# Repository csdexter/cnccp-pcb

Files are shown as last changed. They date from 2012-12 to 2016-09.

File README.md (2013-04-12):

#CNC Control Panel: Schematics and Boards#

(C) 2012 Radu - Eosif Mihailescu <radu.mihailescu@linux360.ro>

All files in this repository except `radu-collected.lbr` are licensed under the
**GNU Generic Public License v3**, a copy of whose text can be accessed
 [here](http://www.gnu.org/licenses/gpl.html).

`radu-collected.lbr` alone is hereby licensed under the **Modified BSD (3-clause) License**, a copy of whose text can be found in the `radu-collected.lbr.license` file.

This repository contains [EDA](http://en.wikipedia.org/wiki/Electronic_design_automation) source files for all of the boards in the *CNC Control Panel* project in CadSoft Eagle 6 format. Only the `.SCH` (schematic) and `.BRD` (board) files are provided as all data needed for manufacturing can easily be derived from the former. No guarantee is made as to which minor version of Eagle was used to save the file, but it *may* be the latest at the time of this writing.

The board description files *may* contain routing information or be supplied unrouted. In the former case, the routing artwork *may* have been generated by either Eagle's internal autorouter or [FreeRouting](http://www.freerouting.net/). A 25mil routing grid and 10/10mil trace/space settings will have been used in both cases.

All files included here are compatible with the free version of Eagle (i.e. describe PCBs having no more than 2 layers and measuring no more than 10cm by 8cm each).

Git tags will be used to mark specific revisions that were actually manufactured so that a correspondence between the evolution of the sources and the status of physical by-products can be maintained.

##WARNING##
*Unless and until explictily noted otherwise, the engineering materials here are laboratory quality and neither intended for manufacturing in production quantities nor for distribution (e.g. as kits) to end-users. The design data here does not explicitly follow any widely-accepted safety/security/EMI regulation or standard, therefore any manufacturing and/or usage in connection with live equipment is entirely at your own risk.*

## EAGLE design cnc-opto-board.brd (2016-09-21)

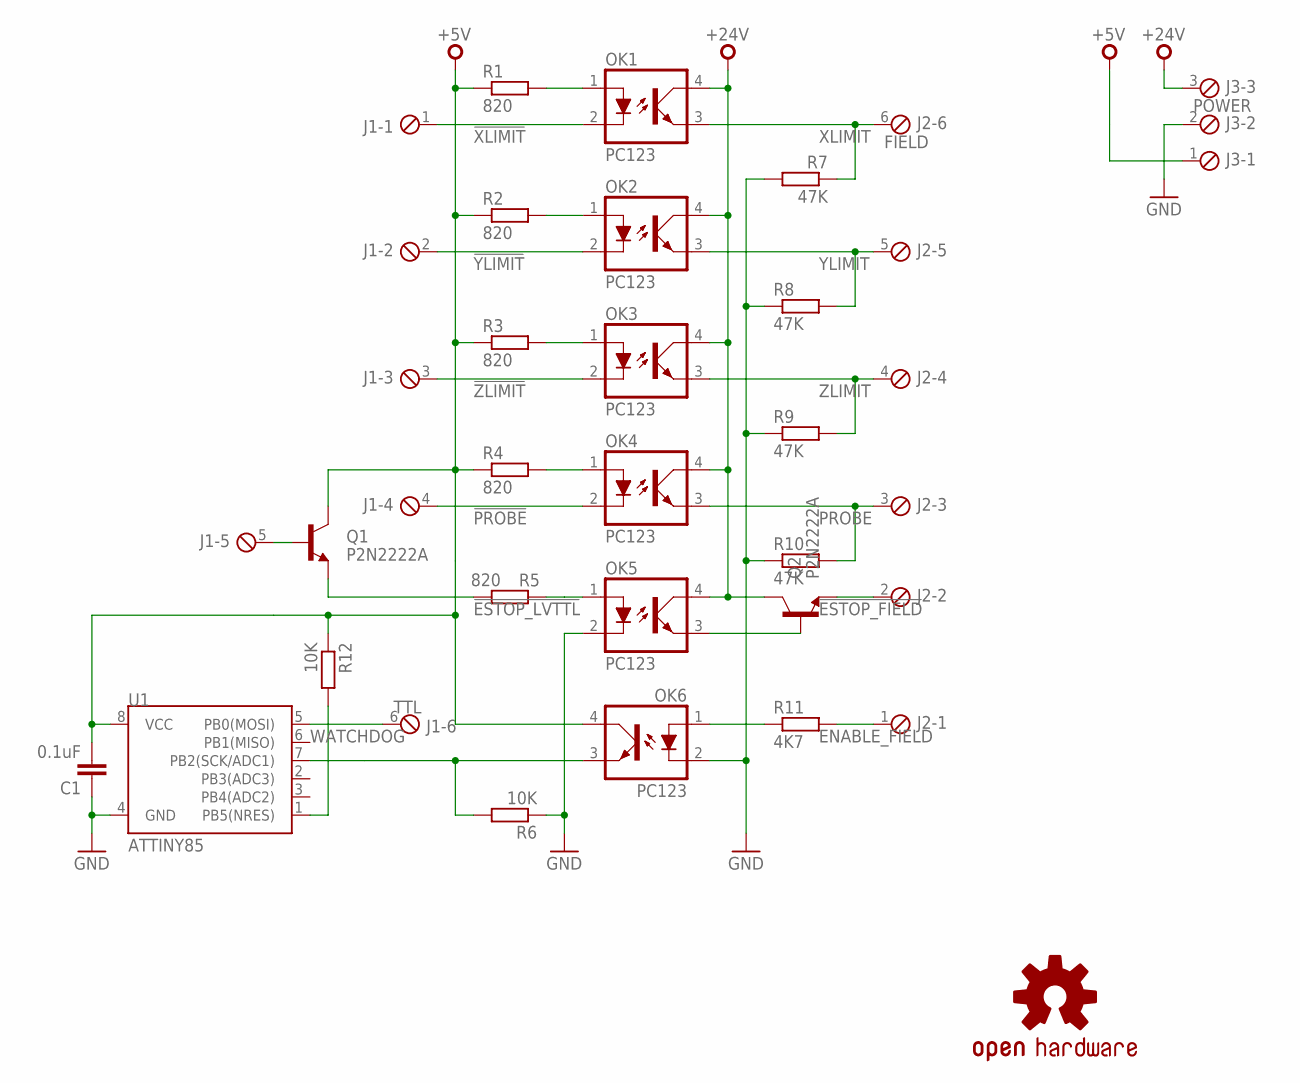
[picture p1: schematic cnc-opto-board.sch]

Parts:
C1: 0.1uF; C050-025X075
J1: TTL; MKDS06
J2: FIELD; MKDS06
J3: POWER; MKDS03
LOGO1: OSHW-LOGOL; OSHW-LOGO-L
OK1, OK2, OK3, OK4, OK5, OK6: PC123; DIL04
Q1, Q2: P2N2222A; TO-92
R1, R2, R3, R4, R5: 820; 0207/10
R6, R12: 10K; 0207/10
R7, R8, R9, R10: 47K; 0207/10
R11: 4K7; 0207/10
U1: ATTINY85; DIL08

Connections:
!ESTOP_FIELD: J2.2, Q2.3 (E)
!ESTOP_LVTTL: OK5.1 (A), R5.1
!PROBE: J1.4, OK4.2 (C)
!XLIMIT: J1.1, OK1.2 (C)
!YLIMIT: J1.2, OK2.2 (C)
!ZLIMIT: J1.3, OK3.2 (C)
+5V: C1.2, J3.1, OK6.4 (COL), Q1.1 (C), R1.1, R2.1, R3.1, R4.1, R12.1, U1.8 (VCC)
+24V: J3.3, OK1.4 (COL), OK2.4 (COL), OK3.4 (COL), OK4.4 (COL), OK5.4 (COL), Q2.1 (C)
ENABLE_FIELD: J2.1, R11.2
ENABLE_TTL: OK6.3 (EMIT), R6.2, U1.7 (PB2(SCK/ADC1))
GND: C1.1, J3.2, OK5.2 (C), OK6.2 (C), R6.1, R7.2, R8.1, R9.1, R10.1, U1.4 (GND)
unnamed: OK1.1 (A), R1.2
unnamed: OK2.1 (A), R2.2
unnamed: OK3.1 (A), R3.2
unnamed: OK4.1 (A), R4.2
unnamed: Q1.3 (E), R5.2
unnamed: OK6.1 (A), R11.1
unnamed: J1.5, Q1.2 (B)
unnamed: OK5.3 (EMIT), Q2.2 (B)
unnamed: R12.2, U1.1 (PB5(NRES))
PROBE: J2.3, OK4.3 (EMIT), R10.2
WATCHDOG: J1.6, U1.5 (PB0(MOSI))
XLIMIT: J2.6, OK1.3 (EMIT), R7.1
YLIMIT: J2.5, OK2.3 (EMIT), R8.2
ZLIMIT: J2.4, OK3.3 (EMIT), R9.2

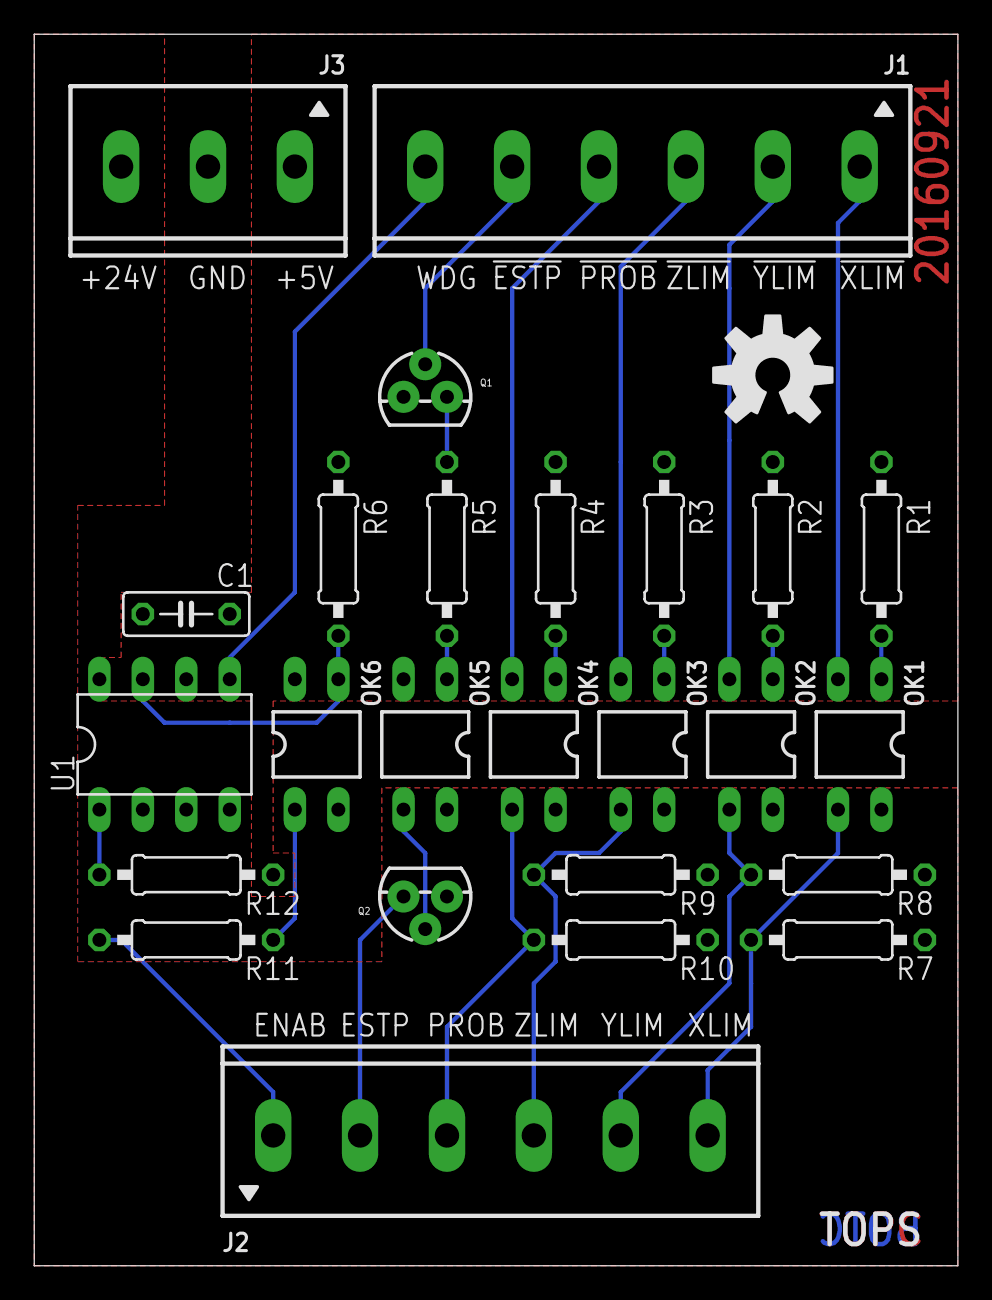
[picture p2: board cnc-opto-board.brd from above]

Board: 2 copper layers, 54.0 x 72.0 mm, 26 parts (0 on the bottom side), 25 nets.

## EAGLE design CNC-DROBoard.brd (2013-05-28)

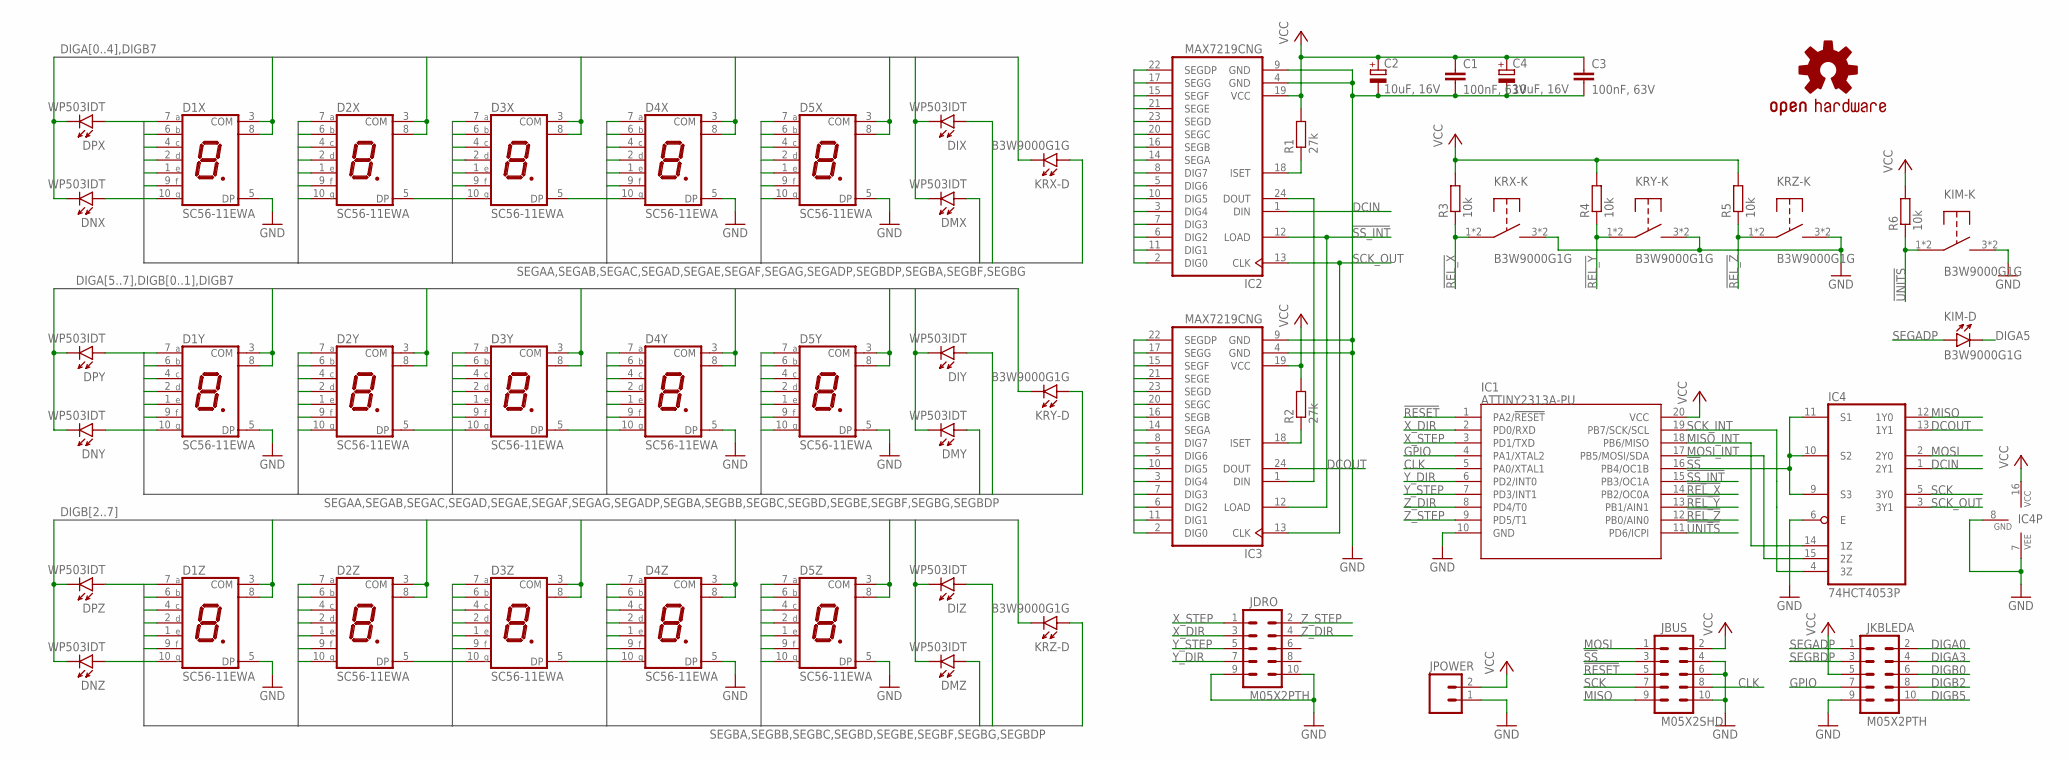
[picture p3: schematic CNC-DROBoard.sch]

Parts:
C1, C3: 100nF, 63V; C050-025X075
C2, C4: 10uF, 16V; E2,5-6E
D1X, D1Y, D1Z, D2X, D2Y, D2Z, D3X, D3Y, D3Z, D4X, D4Y, D4Z, D5X, D5Y, D5Z: SC56-11EWA; SA52-11
DIX: WP503IDT; AXIAL__GENERIC_SQ_5X5
DIY: WP503IDT; AXIAL__GENERIC_SQ_5X5
DIZ: WP503IDT; AXIAL__GENERIC_SQ_5X5
DMX: WP503IDT; AXIAL__GENERIC_SQ_5X5
DMY: WP503IDT; AXIAL__GENERIC_SQ_5X5
DMZ: WP503IDT; AXIAL__GENERIC_SQ_5X5
DNX: WP503IDT; AXIAL__GENERIC_SQ_5X5
DNY: WP503IDT; AXIAL__GENERIC_SQ_5X5
DNZ: WP503IDT; AXIAL__GENERIC_SQ_5X5
DPX: WP503IDT; AXIAL__GENERIC_SQ_5X5
DPY: WP503IDT; AXIAL__GENERIC_SQ_5X5
DPZ: WP503IDT; AXIAL__GENERIC_SQ_5X5
IC1: ATTINY2313A-PU; DIL20
IC2, IC3: MAX7219CNG; DIL24-3
IC4: 74HCT4053P; DIL16
JBUS: M05X2SHD; 2X5-SHROUDED
JDRO: M05X2PTH; AVR_ICSP
JKBLEDA: M05X2PTH; AVR_ICSP
JPOWER: M02POLAR; MOLEX-1X2
KIM: B3W9000G1G; OMRON_B3W90
KRX: B3W9000G1G; OMRON_B3W90
KRY: B3W9000G1G; OMRON_B3W90
KRZ: B3W9000G1G; OMRON_B3W90
R1, R2: 27k; 0207/10
R3, R4, R5, R6: 10k; 0207/10
U$1: SPARKFUN_OSHW-LOGOL; SPARKFUN_OSHW-LOGO-L

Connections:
!REL_X: IC1.14 (PB2/OC0A), KRX.1, KRX.2, R3.1
!REL_Y: IC1.13 (PB1/AIN1), KRY.1, KRY.2, R4.1
!REL_Z: IC1.12 (PB0/AIN0), KRZ.1, KRZ.2, R5.1
!RESET: IC1.1 (PA2/!RESET), JBUS.5
!SS: IC1.16 (PB4/OC1B), IC4.9 (S3), IC4.10 (S2), IC4.11 (S1), JBUS.3
!SS_INT: IC1.15 (PB3/OC1A), IC2.12 (LOAD), IC3.12 (LOAD)
!UNITS: IC1.11 (PD6/ICPI), KIM.1, KIM.2, R6.1
CLK: IC1.5 (PA0/XTAL1), JBUS.8
DCIN: IC2.1 (DIN), IC4.1 (2Y1)
DCOUT: IC3.24 (DOUT), IC4.13 (1Y1)
DIGA0: D1X.3 (COM), D1X.8 (COM), IC2.2 (DIG0), JKBLEDA.2
DIGA1: D2X.3 (COM), D2X.8 (COM), IC2.11 (DIG1)
DIGA2: D3X.3 (COM), D3X.8 (COM), IC2.6 (DIG2)
DIGA3: D4X.3 (COM), D4X.8 (COM), IC2.7 (DIG3), JKBLEDA.4
DIGA4: D5X.3 (COM), D5X.8 (COM), IC2.3 (DIG4), KRX.6 (K)
DIGA5: D1Y.3 (COM), D1Y.8 (COM), IC2.10 (DIG5), KIM.6 (K)
DIGA6: D2Y.3 (COM), D2Y.8 (COM), IC2.5 (DIG6)
DIGA7: D3Y.3 (COM), D3Y.8 (COM), IC2.8 (DIG7)
DIGB0: D4Y.3 (COM), D4Y.8 (COM), IC3.2 (DIG0), JKBLEDA.6
DIGB1: D5Y.3 (COM), D5Y.8 (COM), IC3.11 (DIG1), KRY.6 (K)
DIGB2: D1Z.3 (COM), D1Z.8 (COM), IC3.6 (DIG2), JKBLEDA.8
DIGB3: D2Z.3 (COM), D2Z.8 (COM), IC3.7 (DIG3)
DIGB4: D3Z.3 (COM), D3Z.8 (COM), IC3.3 (DIG4)
DIGB5: D4Z.3 (COM), D4Z.8 (COM), IC3.10 (DIG5), JKBLEDA.10
DIGB6: D5Z.3 (COM), D5Z.8 (COM), IC3.5 (DIG6), KRZ.6 (K)
DIGB7: DIX.2 (K), DIY.2 (K), DIZ.2 (K), DMX.2 (K), DMY.2 (K), DMZ.2 (K), DNX.2 (K), DNY.2 (K), DNZ.2 (K), DPX.2 (K), DPY.2 (K), DPZ.2 (K), IC3.8 (DIG7)
GND: C1.2, C2.-, C3.2, C4.-, D1X.5 (DP), D1Y.5 (DP), D1Z.5 (DP), D4X.5 (DP), D4Y.5 (DP), D4Z.5 (DP), D5X.5 (DP), D5Y.5 (DP), D5Z.5 (DP), IC1.10 (GND), IC2.4 (GND), IC2.9 (GND), IC3.4 (GND), IC3.9 (GND), IC4.6 (E), IC4.7 (VEE), IC4.8 (GND), JBUS.4, JBUS.6, JBUS.10, JDRO.9, JDRO.10, JKBLEDA.9, JPOWER.1, KIM.3, KIM.4, KRX.3, KRX.4, KRY.3, KRY.4, KRZ.3, KRZ.4
GPIO: IC1.4 (PA1/XTAL2), JKBLEDA.7
MISO: IC4.12 (1Y0), JBUS.9
MISO_INT: IC1.18 (PB6/MISO), IC4.14 (1Z)
MOSI: IC4.2 (2Y0), JBUS.1
MOSI_INT: IC1.17 (PB5/MOSI/SDA), IC4.15 (2Z)
unnamed: IC2.24 (DOUT), IC3.1 (DIN)
unnamed: IC2.18 (ISET), R1.1
unnamed: IC3.18 (ISET), R2.1
SCK: IC4.5 (3Y0), JBUS.7
SCK_INT: IC1.19 (PB7/SCK/SCL), IC4.4 (3Z)
SCK_OUT: IC2.13 (CLK), IC3.13 (CLK), IC4.3 (3Y1)
SEGAA: D1X.7 (A), D1Y.7 (A), D2X.7 (A), D2Y.7 (A), D3X.7 (A), D3Y.7 (A), D4X.7 (A), D5X.7 (A), IC2.14 (SEGA)
SEGAB: D1X.6 (B), D1Y.6 (B), D2X.6 (B), D2Y.6 (B), D3X.6 (B), D3Y.6 (B), D4X.6 (B), D5X.6 (B), IC2.16 (SEGB)
SEGAC: D1X.4 (C), D1Y.4 (C), D2X.4 (C), D2Y.4 (C), D3X.4 (C), D3Y.4 (C), D4X.4 (C), D5X.4 (C), IC2.20 (SEGC)
SEGAD: D1X.2 (D), D1Y.2 (D), D2X.2 (D), D2Y.2 (D), D3X.2 (D), D3Y.2 (D), D4X.2 (D), D5X.2 (D), IC2.23 (SEGD)
SEGADP: D2X.5 (DP), D2Y.5 (DP), D3X.5 (DP), D3Y.5 (DP), IC2.22 (SEGDP), JKBLEDA.1, KIM.5 (A), KRX.5 (A)
SEGAE: D1X.1 (E), D1Y.1 (E), D2X.1 (E), D2Y.1 (E), D3X.1 (E), D3Y.1 (E), D4X.1 (E), D5X.1 (E), IC2.21 (SEGE)
SEGAF: D1X.9 (F), D1Y.9 (F), D2X.9 (F), D2Y.9 (F), D3X.9 (F), D3Y.9 (F), D4X.9 (F), D5X.9 (F), IC2.15 (SEGF)
SEGAG: D1X.10 (G), D1Y.10 (G), D2X.10 (G), D2Y.10 (G), D3X.10 (G), D3Y.10 (G), D4X.10 (G), D5X.10 (G), IC2.17 (SEGG)
SEGBA: D1Z.7 (A), D2Z.7 (A), D3Z.7 (A), D4Y.7 (A), D4Z.7 (A), D5Y.7 (A), D5Z.7 (A), DNX.1 (A), IC3.14 (SEGA)
SEGBB: D1Z.6 (B), D2Z.6 (B), D3Z.6 (B), D4Y.6 (B), D4Z.6 (B), D5Y.6 (B), D5Z.6 (B), DPY.1 (A), IC3.16 (SEGB)
SEGBC: D1Z.4 (C), D2Z.4 (C), D3Z.4 (C), D4Y.4 (C), D4Z.4 (C), D5Y.4 (C), D5Z.4 (C), DNY.1 (A), IC3.20 (SEGC)
SEGBD: D1Z.2 (D), D2Z.2 (D), D3Z.2 (D), D4Y.2 (D), D4Z.2 (D), D5Y.2 (D), D5Z.2 (D), DPZ.1 (A), IC3.23 (SEGD)
SEGBDP: D2Z.5 (DP), D3Z.5 (DP), DPX.1 (A), IC3.22 (SEGDP), JKBLEDA.3, KRY.5 (A), KRZ.5 (A)
SEGBE: D1Z.1 (E), D2Z.1 (E), D3Z.1 (E), D4Y.1 (E), D4Z.1 (E), D5Y.1 (E), D5Z.1 (E), DNZ.1 (A), IC3.21 (SEGE)
SEGBF: D1Z.9 (F), D2Z.9 (F), D3Z.9 (F), D4Y.9 (F), D4Z.9 (F), D5Y.9 (F), D5Z.9 (F), DIX.1 (A), DIY.1 (A), DIZ.1 (A), IC3.15 (SEGF)
SEGBG: D1Z.10 (G), D2Z.10 (G), D3Z.10 (G), D4Y.10 (G), D4Z.10 (G), D5Y.10 (G), D5Z.10 (G), DMX.1 (A), DMY.1 (A), DMZ.1 (A), IC3.17 (SEGG)
VCC: C1.1, C2.+, C3.1, C4.+, IC1.20 (VCC), IC2.19 (VCC), IC3.19 (VCC), IC4.16 (VCC), JBUS.2, JKBLEDA.5, JPOWER.2, R1.2, R2.2, R3.2, R4.2, R5.2, R6.2
X_DIR: IC1.2 (PD0/RXD), JDRO.3
X_STEP: IC1.3 (PD1/TXD), JDRO.1
Y_DIR: IC1.6 (PD2/INT0), JDRO.7
Y_STEP: IC1.7 (PD3/INT1), JDRO.5
Z_DIR: IC1.8 (PD4/T0), JDRO.4
Z_STEP: IC1.9 (PD5/T1), JDRO.2

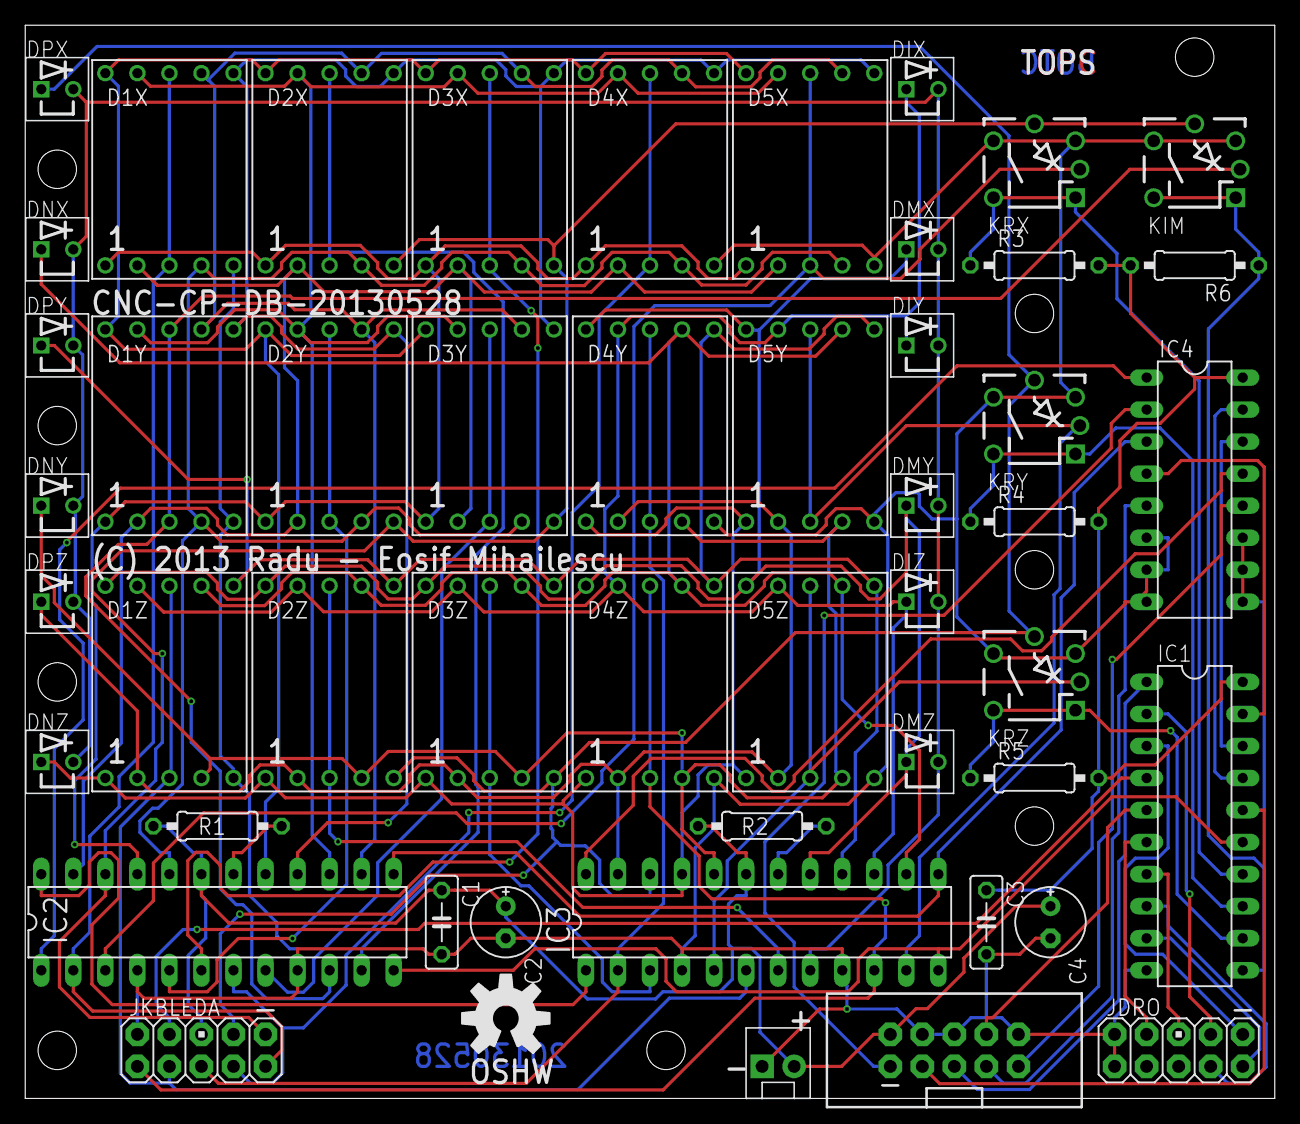
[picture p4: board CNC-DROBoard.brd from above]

Board: 2 copper layers, 99.1 x 85.1 mm, 50 parts (0 on the bottom side), 61 nets.

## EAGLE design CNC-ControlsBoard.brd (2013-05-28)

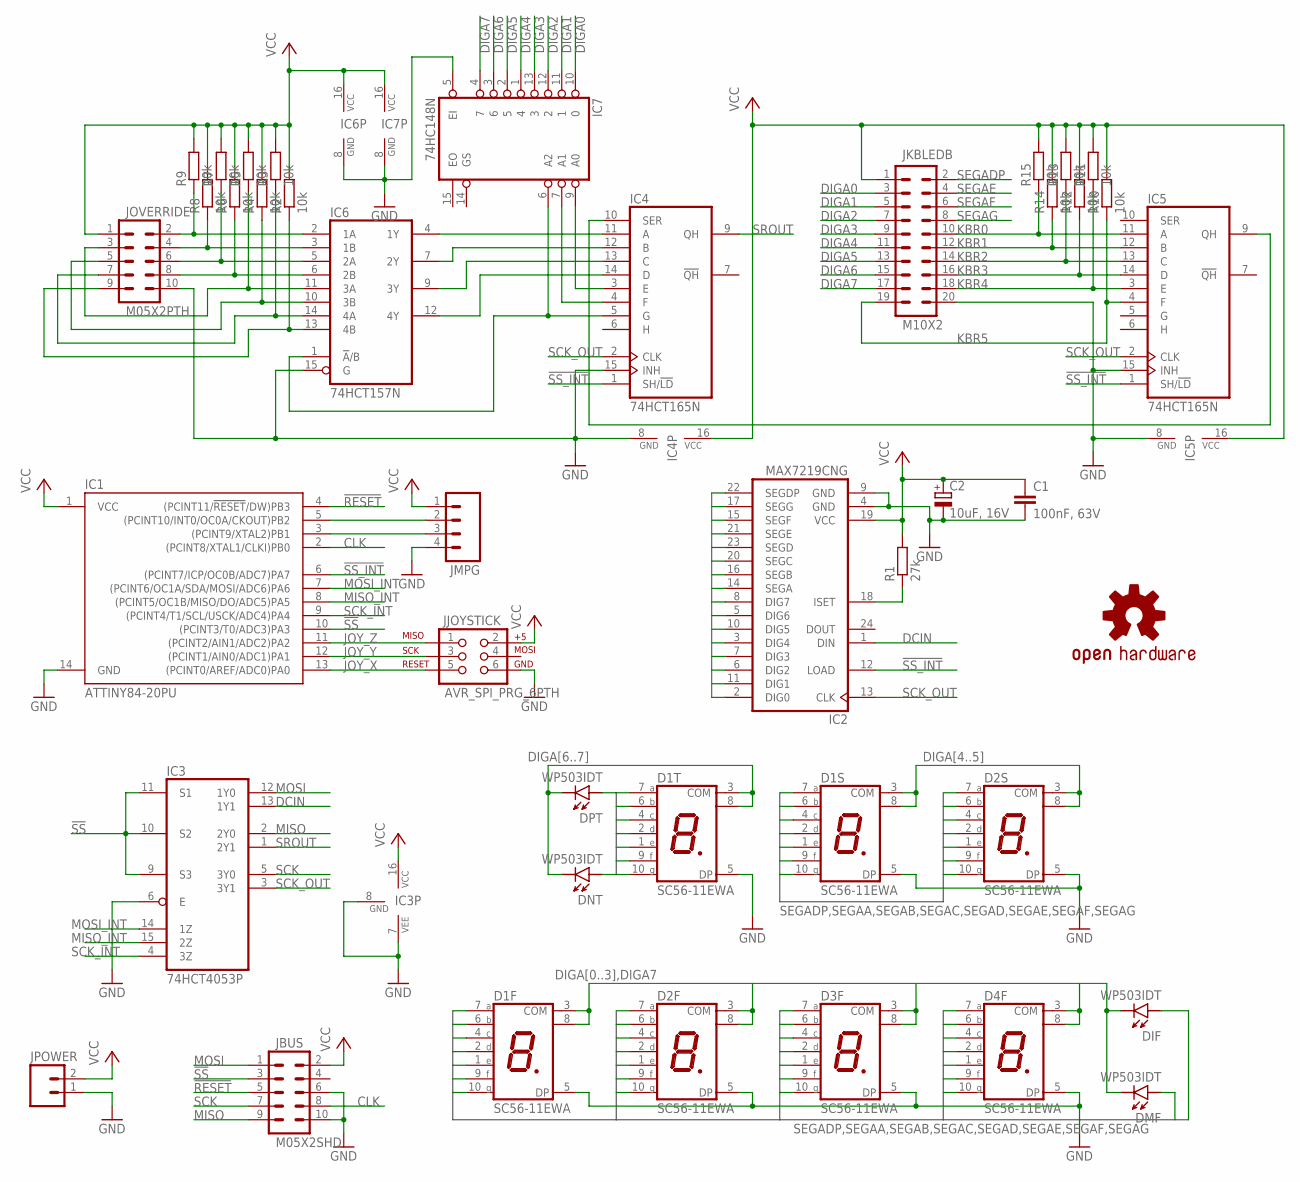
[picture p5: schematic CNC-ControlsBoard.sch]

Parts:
C1: 100nF, 63V; C050-025X075
C2: 10uF, 16V; E2,5-6E
D1F, D1S, D1T, D2F, D2S, D3F, D4F: SC56-11EWA; SA52-11
DIF: WP503IDT; AXIAL__GENERIC_SQ_5X5
DMF: WP503IDT; AXIAL__GENERIC_SQ_5X5
DNT: WP503IDT; AXIAL__GENERIC_SQ_5X5
DPT: WP503IDT; AXIAL__GENERIC_SQ_5X5
IC1: ATTINY84-20PU; DIL14
IC2: MAX7219CNG; DIL24-3
IC3: 74HCT4053P; DIL16
IC4, IC5: 74HCT165N; DIL16
IC6: 74HCT157N; DIL16
IC7: 74HC148N; DIL16
JBUS: M05X2SHD; 2X5-SHROUDED
JJOYSTICK: AVR_SPI_PRG_6PTH; 2X3
JKBLEDB: M10X2; 2X10
JMPG: M04PTH; 1X04
JOVERRIDE: M05X2PTH; AVR_ICSP
JPOWER: M02POLAR; MOLEX-1X2
R1: 27k; 0207/10
R2, R3, R4, R5, R6, R7, R8, R9, R10, R11, R12, R13, R14, R15: 10k; 0207/10
U$1: SPARKFUN_OSHW-LOGOL; SPARKFUN_OSHW-LOGO-L

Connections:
!RESET: IC1.4 ((PCINT11/!RESET!/DW)PB3), JBUS.5
!SS: IC1.10 ((PCINT3/T0/ADC3)PA3), IC3.9 (S3), IC3.10 (S2), IC3.11 (S1), JBUS.3
!SS_INT: IC1.6 ((PCINT7/ICP/OC0B/ADC7)PA7), IC2.12 (LOAD), IC4.1 (SH/!LD), IC5.1 (SH/!LD)
CLK: IC1.2 ((PCINT8/XTAL1/CLKI)PB0), JBUS.8
DCIN: IC2.1 (DIN), IC3.13 (1Y1)
DIGA0: D1F.3 (COM), D1F.8 (COM), IC2.2 (DIG0), IC7.10 (0), JKBLEDB.3
DIGA1: D2F.3 (COM), D2F.8 (COM), IC2.11 (DIG1), IC7.11 (1), JKBLEDB.5
DIGA2: D3F.3 (COM), D3F.8 (COM), IC2.6 (DIG2), IC7.12 (2), JKBLEDB.7
DIGA3: D4F.3 (COM), D4F.8 (COM), IC2.7 (DIG3), IC7.13 (3), JKBLEDB.9
DIGA4: D1S.3 (COM), D1S.8 (COM), IC2.3 (DIG4), IC7.1 (4), JKBLEDB.11
DIGA5: D2S.3 (COM), D2S.8 (COM), IC2.10 (DIG5), IC7.2 (5), JKBLEDB.13
DIGA6: D1T.3 (COM), D1T.8 (COM), IC2.5 (DIG6), IC7.3 (6), JKBLEDB.15
DIGA7: DIF.2 (K), DMF.2 (K), DNT.2 (K), DPT.2 (K), IC2.8 (DIG7), IC7.4 (7), JKBLEDB.17
FOA1: IC6.13 (4B), JOVERRIDE.9, R2.1
FOB1: IC6.14 (4A), JOVERRIDE.7, R3.1
FOC1: IC6.10 (3B), JOVERRIDE.5, R4.1
FOD1: IC6.11 (3A), JOVERRIDE.3, R5.1
GND: C1.2, C2.-, D1F.5 (DP), D1S.5 (DP), D1T.5 (DP), D2F.5 (DP), D2S.5 (DP), D3F.5 (DP), D4F.5 (DP), IC1.14 (GND), IC2.4 (GND), IC2.9 (GND), IC3.6 (E), IC3.7 (VEE), IC3.8 (GND), IC4.8 (GND), IC4.15 (INH), IC5.8 (GND), IC5.15 (INH), IC6.8 (GND), IC6.15 (G), IC7.5 (EI), IC7.8 (GND), JBUS.6, JBUS.10, JJOYSTICK.6, JKBLEDB.20, JMPG.4, JOVERRIDE.10, JPOWER.1
JOY_X: IC1.13 ((PCINT0/AREF/ADC0)PA0), JJOYSTICK.5
JOY_Y: IC1.12 ((PCINT1/AIN0/ADC1)PA1), JJOYSTICK.3
JOY_Z: IC1.11 ((PCINT2/AIN1/ADC2)PA2), JJOYSTICK.1
KBR0: IC5.11 (A), JKBLEDB.10, R15.1
KBR1: IC5.12 (B), JKBLEDB.12, R14.1
KBR2: IC5.13 (C), JKBLEDB.14, R13.1
KBR3: IC5.14 (D), JKBLEDB.16, R12.1
KBR4: IC5.3 (E), JKBLEDB.18, R11.1
KBR5: IC5.4 (F), JKBLEDB.19, R10.1
MISO: IC3.2 (2Y0), JBUS.9
MISO_INT: IC1.8 ((PCINT5/OC1B/MISO/DO/ADC5)PA5), IC3.15 (2Z)
MOSI: IC3.12 (1Y0), JBUS.1
MOSI_INT: IC1.7 ((PCINT6/OC1A/SDA/MOSI/ADC6)PA6), IC3.14 (1Z)
unnamed: IC4.10 (SER), IC5.9 (QH)
unnamed: IC4.11 (A), IC6.4 (1Y)
unnamed: IC4.12 (B), IC6.7 (2Y)
unnamed: IC1.5 ((PCINT10/INT0/OC0A/CKOUT)PB2), JMPG.2
unnamed: IC1.3 ((PCINT9/XTAL2)PB1), JMPG.3
unnamed: IC4.13 (C), IC6.9 (3Y)
unnamed: IC4.14 (D), IC6.12 (4Y)
unnamed: IC4.3 (E), IC7.9 (A0)
unnamed: IC4.4 (F), IC7.7 (A1)
unnamed: IC4.5 (G), IC6.1 (!A!/B), IC7.6 (A2)
unnamed: IC2.18 (ISET), R1.1
SCK: IC3.5 (3Y0), JBUS.7
SCK_INT: IC1.9 ((PCINT4/T1/SCL/USCK/ADC4)PA4), IC3.4 (3Z)
SCK_OUT: IC2.13 (CLK), IC3.3 (3Y1), IC4.2 (CLK), IC5.2 (CLK)
SEGAA: D1F.7 (A), D1S.7 (A), D1T.7 (A), D2F.7 (A), D2S.7 (A), D3F.7 (A), D4F.7 (A), DPT.1 (A), IC2.14 (SEGA)
SEGAB: D1F.6 (B), D1S.6 (B), D1T.6 (B), D2F.6 (B), D2S.6 (B), D3F.6 (B), D4F.6 (B), DNT.1 (A), IC2.16 (SEGB)
SEGAC: D1F.4 (C), D1S.4 (C), D1T.4 (C), D2F.4 (C), D2S.4 (C), D3F.4 (C), D4F.4 (C), DIF.1 (A), IC2.20 (SEGC)
SEGAD: D1F.2 (D), D1S.2 (D), D1T.2 (D), D2F.2 (D), D2S.2 (D), D3F.2 (D), D4F.2 (D), DMF.1 (A), IC2.23 (SEGD)
SEGADP: IC2.22 (SEGDP), JKBLEDB.2
SEGAE: D1F.1 (E), D1S.1 (E), D1T.1 (E), D2F.1 (E), D2S.1 (E), D3F.1 (E), D4F.1 (E), IC2.21 (SEGE), JKBLEDB.4
SEGAF: D1F.9 (F), D1S.9 (F), D1T.9 (F), D2F.9 (F), D2S.9 (F), D3F.9 (F), D4F.9 (F), IC2.15 (SEGF), JKBLEDB.6
SEGAG: D1F.10 (G), D1S.10 (G), D1T.10 (G), D2F.10 (G), D2S.10 (G), D3F.10 (G), D4F.10 (G), IC2.17 (SEGG), JKBLEDB.8
SOA1: IC6.6 (2B), JOVERRIDE.8, R6.1
SOB1: IC6.5 (2A), JOVERRIDE.6, R7.1
SOC1: IC6.3 (1B), JOVERRIDE.4, R8.1
SOD1: IC6.2 (1A), JOVERRIDE.2, R9.1
SROUT: IC3.1 (2Y1), IC4.9 (QH)
VCC: C1.1, C2.+, IC1.1 (VCC), IC2.19 (VCC), IC3.16 (VCC), IC4.16 (VCC), IC5.16 (VCC), IC6.16 (VCC), IC7.16 (VCC), JBUS.2, JJOYSTICK.2, JKBLEDB.1, JMPG.1, JOVERRIDE.1, JPOWER.2, R1.2, R2.2, R3.2, R4.2, R5.2, R6.2, R7.2, R8.2, R9.2, R10.2, R11.2, R12.2, R13.2, R14.2, R15.2

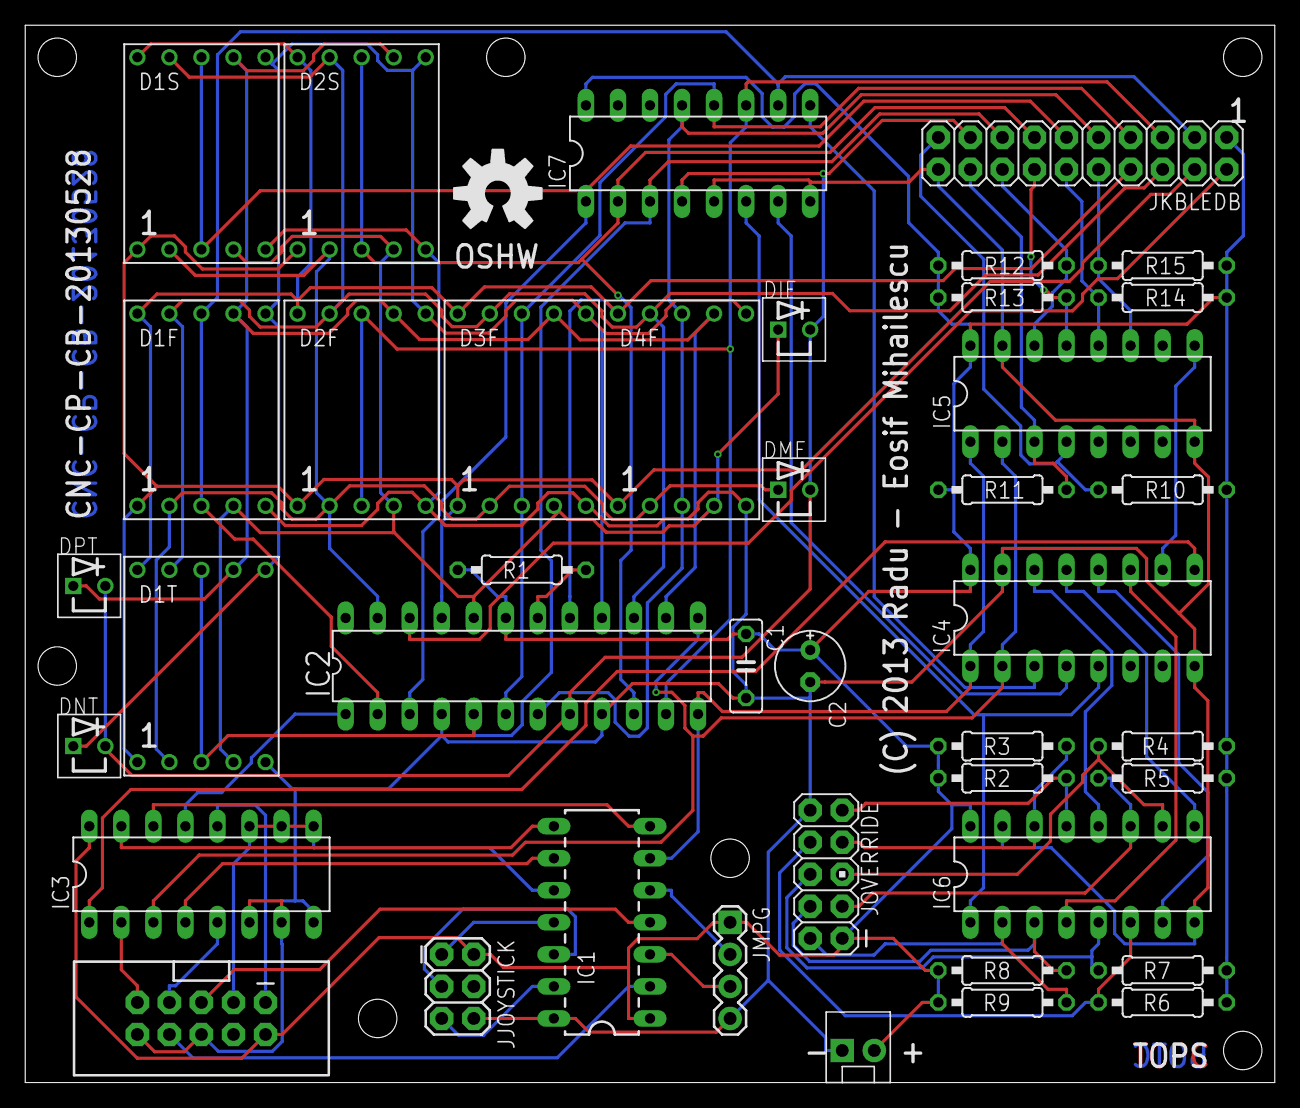
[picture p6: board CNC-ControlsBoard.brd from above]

Board: 2 copper layers, 99.1 x 83.8 mm, 42 parts (0 on the bottom side), 59 nets.

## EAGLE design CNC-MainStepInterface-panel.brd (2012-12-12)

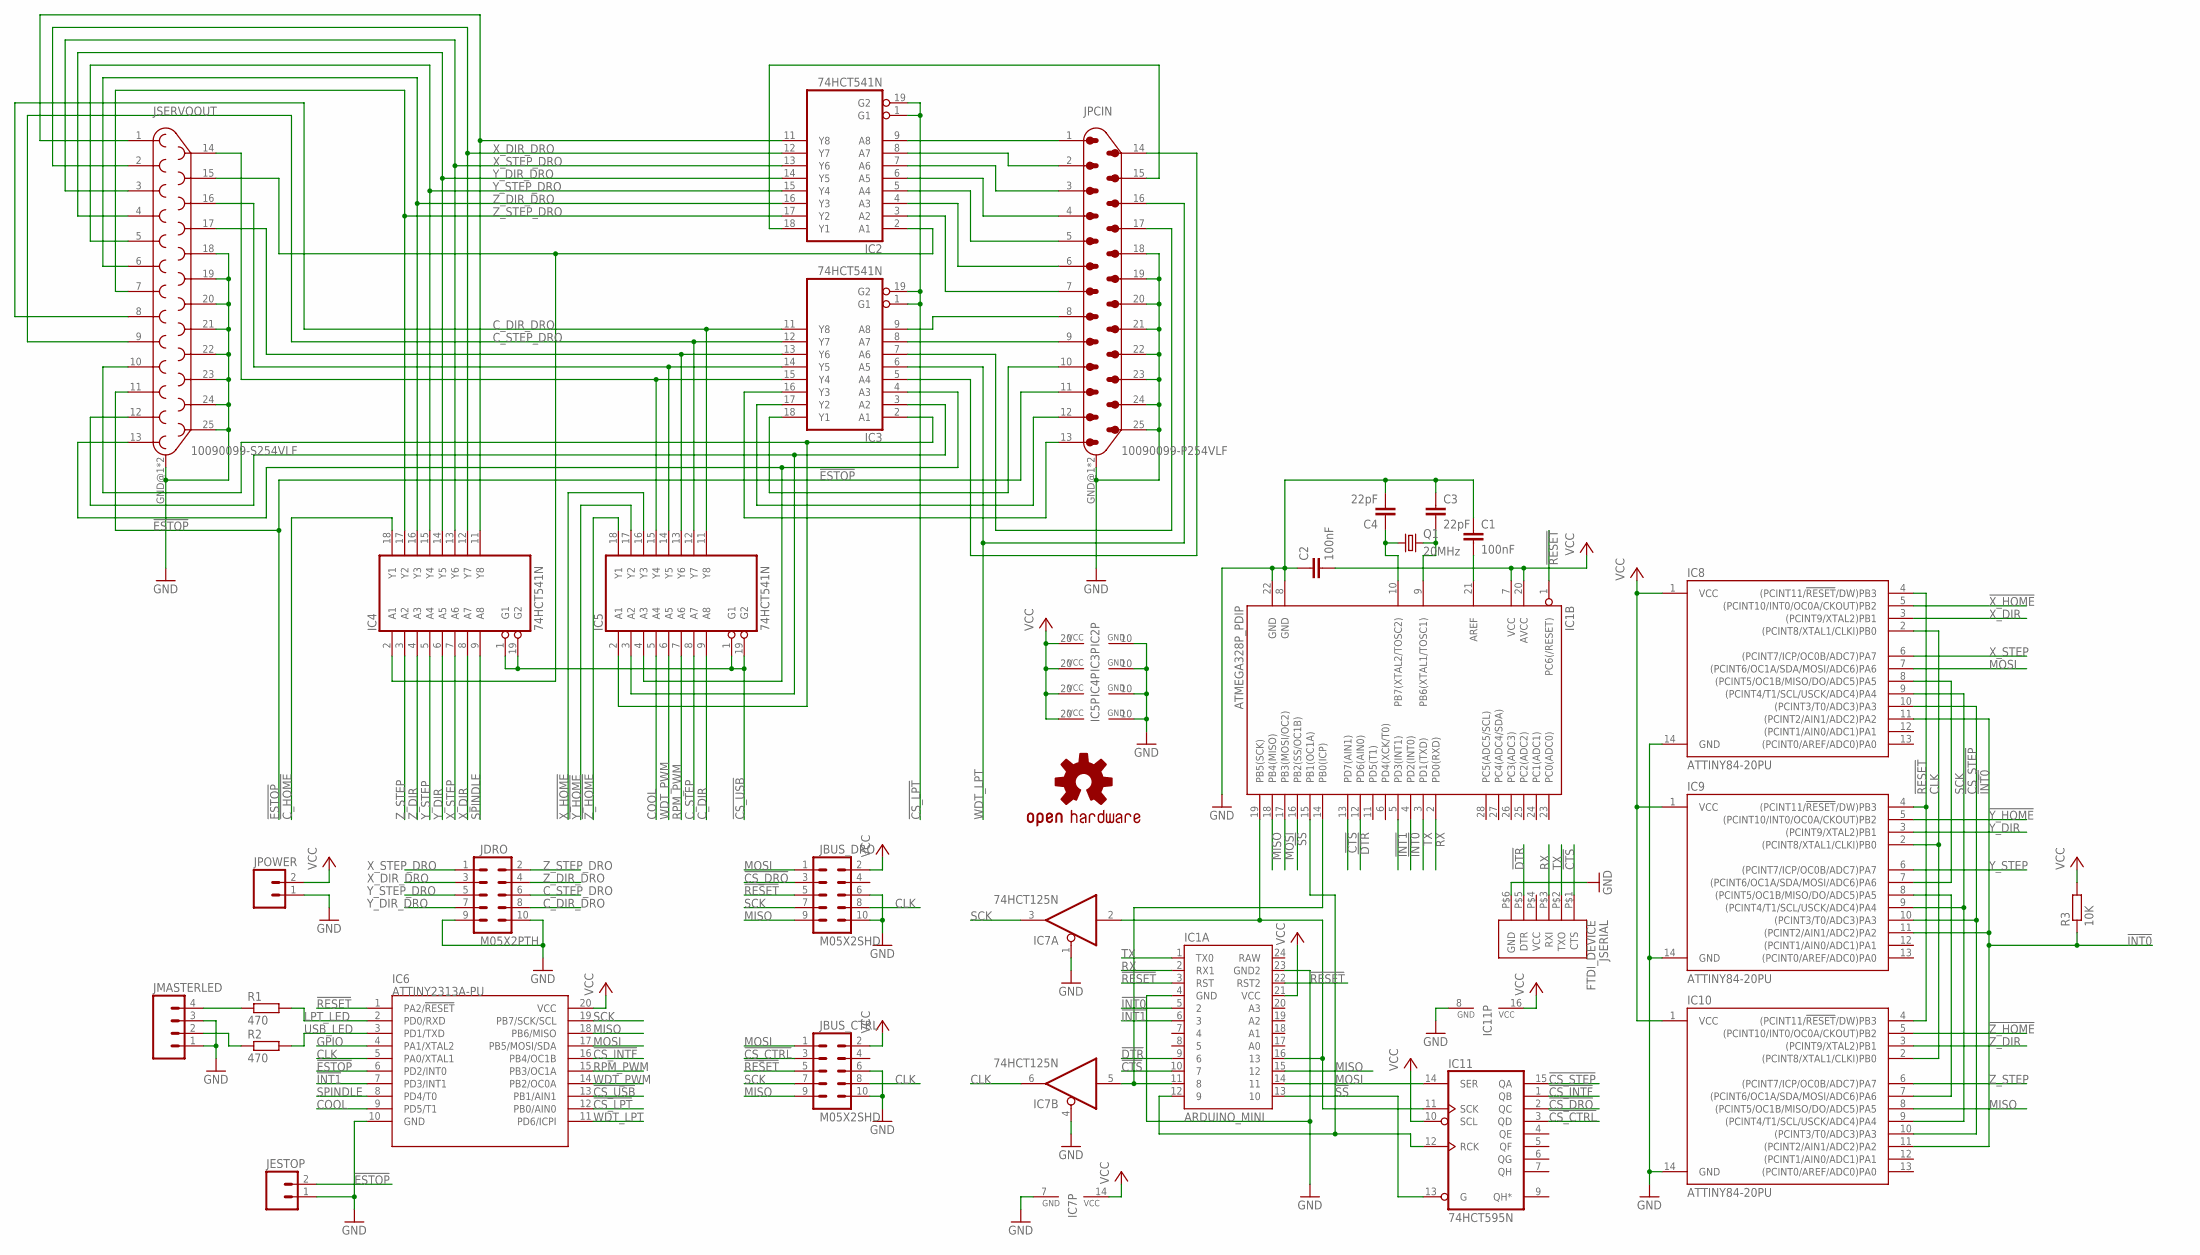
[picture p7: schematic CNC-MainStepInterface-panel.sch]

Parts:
C1, C2: 100nF; C050-025X075
C3, C4: 22pF; C050-025X075
IC1A: ARDUINO_MINI
IC1B: ATMEGA328P_PDIP; DIL28-3
IC2, IC3, IC4, IC5: 74HCT541N; DIL20
IC6: ATTINY2313A-PU; DIL20
IC7: 74HCT125N; DIL14
IC8, IC9, IC10: ATTINY84-20PU; DIL14
IC11: 74HCT595N; DIL16
JBUS_CTRL: M05X2SHD; 2X5-SHROUDED
JBUS_DRO: M05X2SHD; 2X5-SHROUDED
JDRO: M05X2PTH; AVR_ICSP
JESTOP: M02PTH; 1X02
JMASTERLED: M04PTH; 1X04
JPCIN: 10090099-P254VLF
JPOWER: M02POLAR; MOLEX-1X2
JSERIAL: FTDI_DEVICE; FTDI_DEVICE_SIDE
JSERVOOUT: 10090099-S254VLF
Q1: 20MHz; HC49U-V
R1, R2: 470; 0207/10
R3: 10K; 0207/10
U$1: SPARKFUN_OSHW-LOGOL; SPARKFUN_OSHW-LOGO-L

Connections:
!CS_CTRL: IC11.3 (QD), JBUS_CTRL.3
!CS_DRO: IC11.2 (QC), JBUS_DRO.3
!CS_INTF: IC6.16 (PB4/OC1B), IC11.1 (QB)
!CS_LPT: IC2.1 (G1), IC2.19 (G2), IC3.1 (G1), IC3.19 (G2), IC6.12 (PB0/AIN0)
!CS_STEP: IC8.10 ((PCINT3/T0/ADC3)PA3), IC9.10 ((PCINT3/T0/ADC3)PA3), IC10.10 ((PCINT3/T0/ADC3)PA3), IC11.15 (QA)
!CS_USB: IC4.1 (G1), IC4.19 (G2), IC5.1 (G1), IC5.19 (G2), IC6.13 (PB1/AIN1)
!CTS: IC1A.10 (7), IC1B.13 (PD7(AIN1)), JSERIAL.P$1 (CTS)
!C_HOME: IC4.18 (Y1)
!DTR: IC1A.9 (6), IC1B.12 (PD6(AIN0)), JSERIAL.P$5 (DTR)
!ESTOP: IC6.6 (PD2/INT0), JESTOP.2, JPCIN.11, JSERVOOUT.11
!INT0: IC1A.5 (2), IC1B.4 (PD2(INT0)), IC8.11 ((PCINT2/AIN1/ADC2)PA2), IC9.11 ((PCINT2/AIN1/ADC2)PA2), IC10.11 ((PCINT2/AIN1/ADC2)PA2), R3.1
!INT1: IC1A.6 (3), IC1B.5 (PD3(INT1)), IC6.7 (PD3/INT1)
!RESET: IC1A.3 (RST), IC1A.22 (RST2), IC1B.1 (PC6(/RESET)), IC6.1 (PA2/!RESET), IC8.4 ((PCINT11/!RESET!/DW)PB3), IC9.4 ((PCINT11/!RESET!/DW)PB3), IC10.4 ((PCINT11/!RESET!/DW)PB3), JBUS_CTRL.5, JBUS_DRO.5
!SS: IC1A.13 (10), IC1B.16 (PB2(SS/OC1B)), IC11.13 (G)
!X_HOME: IC5.16 (Y3), IC8.5 ((PCINT10/INT0/OC0A/CKOUT)PB2)
!Y_HOME: IC5.17 (Y2), IC9.5 ((PCINT10/INT0/OC0A/CKOUT)PB2)
!Z_HOME: IC5.18 (Y1), IC10.5 ((PCINT10/INT0/OC0A/CKOUT)PB2)
CLK: IC6.5 (PA0/XTAL1), IC7.6 (O), IC8.2 ((PCINT8/XTAL1/CLKI)PB0), IC9.2 ((PCINT8/XTAL1/CLKI)PB0), IC10.2 ((PCINT8/XTAL1/CLKI)PB0), JBUS_CTRL.8, JBUS_DRO.8
CLK_INT: IC1A.11 (8), IC1B.14 (PB0(ICP)), IC7.5 (I)
COOL: IC5.5 (A4), IC6.9 (PD5/T1)
C_DIR: IC5.9 (A8)
C_DIR_DRO: IC3.11 (Y8), IC5.11 (Y8), JDRO.8, JSERVOOUT.8
C_STEP: IC5.8 (A7)
C_STEP_DRO: IC3.12 (Y7), IC5.12 (Y7), JDRO.6, JSERVOOUT.9
GND: C1.1, C2.1, C3.1, C4.2, IC1A.4 (GND), IC1A.23 (GND2), IC1B.8 (GND), IC1B.22 (GND), IC2.10 (GND), IC3.10 (GND), IC4.10 (GND), IC5.10 (GND), IC6.10 (GND), IC7.1 (OE), IC7.4 (OE), IC7.7 (GND), IC8.14 (GND), IC9.14 (GND), IC10.14 (GND), IC11.8 (GND), JBUS_CTRL.6, JBUS_CTRL.10, JBUS_DRO.6, JBUS_DRO.10, JDRO.9, JDRO.10, JESTOP.1, JMASTERLED.1, JMASTERLED.3, JPCIN.18, JPCIN.19, JPCIN.20, JPCIN.21, JPCIN.22, JPCIN.23, JPCIN.24, JPCIN.25, JPCIN.GND@1 (GND), JPCIN.GND@2 (GND), JPOWER.1, JSERIAL.P$6 (GND), JSERVOOUT.18, JSERVOOUT.19, JSERVOOUT.20, JSERVOOUT.21, JSERVOOUT.22, JSERVOOUT.23, JSERVOOUT.24, JSERVOOUT.25, JSERVOOUT.GND@1 (GND), JSERVOOUT.GND@2 (GND)
GPIO: IC6.4 (PA1/XTAL2)
LPT_LED: IC6.2 (PD0/RXD), R1.2
MISO: IC1A.15 (12), IC1B.18 (PB4(MISO)), IC6.18 (PB6/MISO), IC10.8 ((PCINT5/OC1B/MISO/DO/ADC5)PA5), JBUS_CTRL.9, JBUS_DRO.9
MISO_1: IC8.8 ((PCINT5/OC1B/MISO/DO/ADC5)PA5), IC9.7 ((PCINT6/OC1A/SDA/MOSI/ADC6)PA6)
MISO_2: IC9.8 ((PCINT5/OC1B/MISO/DO/ADC5)PA5), IC10.7 ((PCINT6/OC1A/SDA/MOSI/ADC6)PA6)
MOSI: IC1A.14 (11), IC1B.17 (PB3(MOSI/OC2)), IC6.17 (PB5/MOSI/SDA), IC8.7 ((PCINT6/OC1A/SDA/MOSI/ADC6)PA6), IC11.14 (SER), JBUS_CTRL.1, JBUS_DRO.1
unnamed: IC2.9 (A8), JPCIN.1
unnamed: IC2.8 (A7), JPCIN.2
unnamed: IC2.7 (A6), JPCIN.3
unnamed: IC2.6 (A5), JPCIN.4
unnamed: IC2.5 (A4), JPCIN.5
unnamed: IC2.4 (A3), JPCIN.6
unnamed: IC2.3 (A2), JPCIN.7
unnamed: IC3.9 (A8), JPCIN.8
unnamed: IC3.8 (A7), JPCIN.9
unnamed: IC3.5 (A4), JPCIN.14
unnamed: JMASTERLED.2, R2.1
unnamed: IC3.2 (A1), IC5.2 (A1), JSERVOOUT.10
unnamed: IC3.3 (A2), IC5.3 (A2), JSERVOOUT.12
unnamed: IC3.7 (A6), JPCIN.17
unnamed: IC3.4 (A3), IC5.4 (A3), JSERVOOUT.13
unnamed: JMASTERLED.4, R1.1
unnamed: IC3.16 (Y3), JPCIN.13
unnamed: IC3.17 (Y2), JPCIN.12
unnamed: IC2.18 (Y1), JPCIN.15
unnamed: C1.2, IC1B.21 (AREF)
unnamed: IC3.18 (Y1), JPCIN.10
unnamed: IC3.15 (Y4), IC5.15 (Y4), JSERVOOUT.14
unnamed: IC3.14 (Y5), IC5.14 (Y5), JSERVOOUT.16
unnamed: IC3.13 (Y6), IC5.13 (Y6), JSERVOOUT.17
unnamed: IC2.2 (A1), IC4.2 (A1), JSERVOOUT.15
unnamed: IC2.11 (Y8), IC4.11 (Y8), JSERVOOUT.1
RPM_PWM: IC5.7 (A6), IC6.15 (PB3/OC1A)
RX: IC1A.2 (RX1), IC1B.2 (PD0(RXD)), JSERIAL.P$3 (RXI)
SADDR: IC1A.12 (9), IC1B.15 (PB1(OC1A)), IC11.12 (RCK)
SCK: IC6.19 (PB7/SCK/SCL), IC7.3 (O), IC8.9 ((PCINT4/T1/SCL/USCK/ADC4)PA4), IC9.9 ((PCINT4/T1/SCL/USCK/ADC4)PA4), IC10.9 ((PCINT4/T1/SCL/USCK/ADC4)PA4), JBUS_CTRL.7, JBUS_DRO.7
SCK_INT: IC1A.16 (13), IC1B.19 (PB5(SCK)), IC7.2 (I), IC11.11 (SCK)
SPINDLE: IC4.9 (A8), IC6.8 (PD4/T0)
TX: IC1A.1 (TX0), IC1B.3 (PD1(TXD)), JSERIAL.P$2 (TXO)
USB_LED: IC6.3 (PD1/TXD), R2.2
VCC: C2.2, IC1A.21 (VCC), IC1B.7 (VCC), IC1B.20 (AVCC), IC2.20 (VCC), IC3.20 (VCC), IC4.20 (VCC), IC5.20 (VCC), IC6.20 (VCC), IC7.14 (VCC), IC8.1 (VCC), IC9.1 (VCC), IC10.1 (VCC), IC11.10 (SCL), IC11.16 (VCC), JBUS_CTRL.2, JBUS_DRO.2, JPOWER.2, R3.2
WDT_LPT: IC3.6 (A5), IC6.11 (PD6/ICPI), JPCIN.16
WDT_PWM: IC5.6 (A5), IC6.14 (PB2/OC0A)
XTAL1: C4.1, IC1B.10 (PB7(XTAL2/TOSC2)), Q1.1
XTAL2: C3.2, IC1B.9 (PB6(XTAL1/TOSC1)), Q1.2
X_DIR: IC4.8 (A7), IC8.3 ((PCINT9/XTAL2)PB1)
X_DIR_DRO: IC2.12 (Y7), IC4.12 (Y7), JDRO.3, JSERVOOUT.2
X_STEP: IC4.7 (A6), IC8.6 ((PCINT7/ICP/OC0B/ADC7)PA7)
X_STEP_DRO: IC2.13 (Y6), IC4.13 (Y6), JDRO.1, JSERVOOUT.3
Y_DIR: IC4.6 (A5), IC9.3 ((PCINT9/XTAL2)PB1)
Y_DIR_DRO: IC2.14 (Y5), IC4.14 (Y5), JDRO.7, JSERVOOUT.4
Y_STEP: IC4.5 (A4), IC9.6 ((PCINT7/ICP/OC0B/ADC7)PA7)
Y_STEP_DRO: IC2.15 (Y4), IC4.15 (Y4), JDRO.5, JSERVOOUT.5
Z_DIR: IC4.4 (A3), IC10.3 ((PCINT9/XTAL2)PB1)
Z_DIR_DRO: IC2.16 (Y3), IC4.16 (Y3), JDRO.4, JSERVOOUT.6
Z_STEP: IC4.3 (A2), IC10.6 ((PCINT7/ICP/OC0B/ADC7)PA7)
Z_STEP_DRO: IC2.17 (Y2), IC4.17 (Y2), JDRO.2, JSERVOOUT.7

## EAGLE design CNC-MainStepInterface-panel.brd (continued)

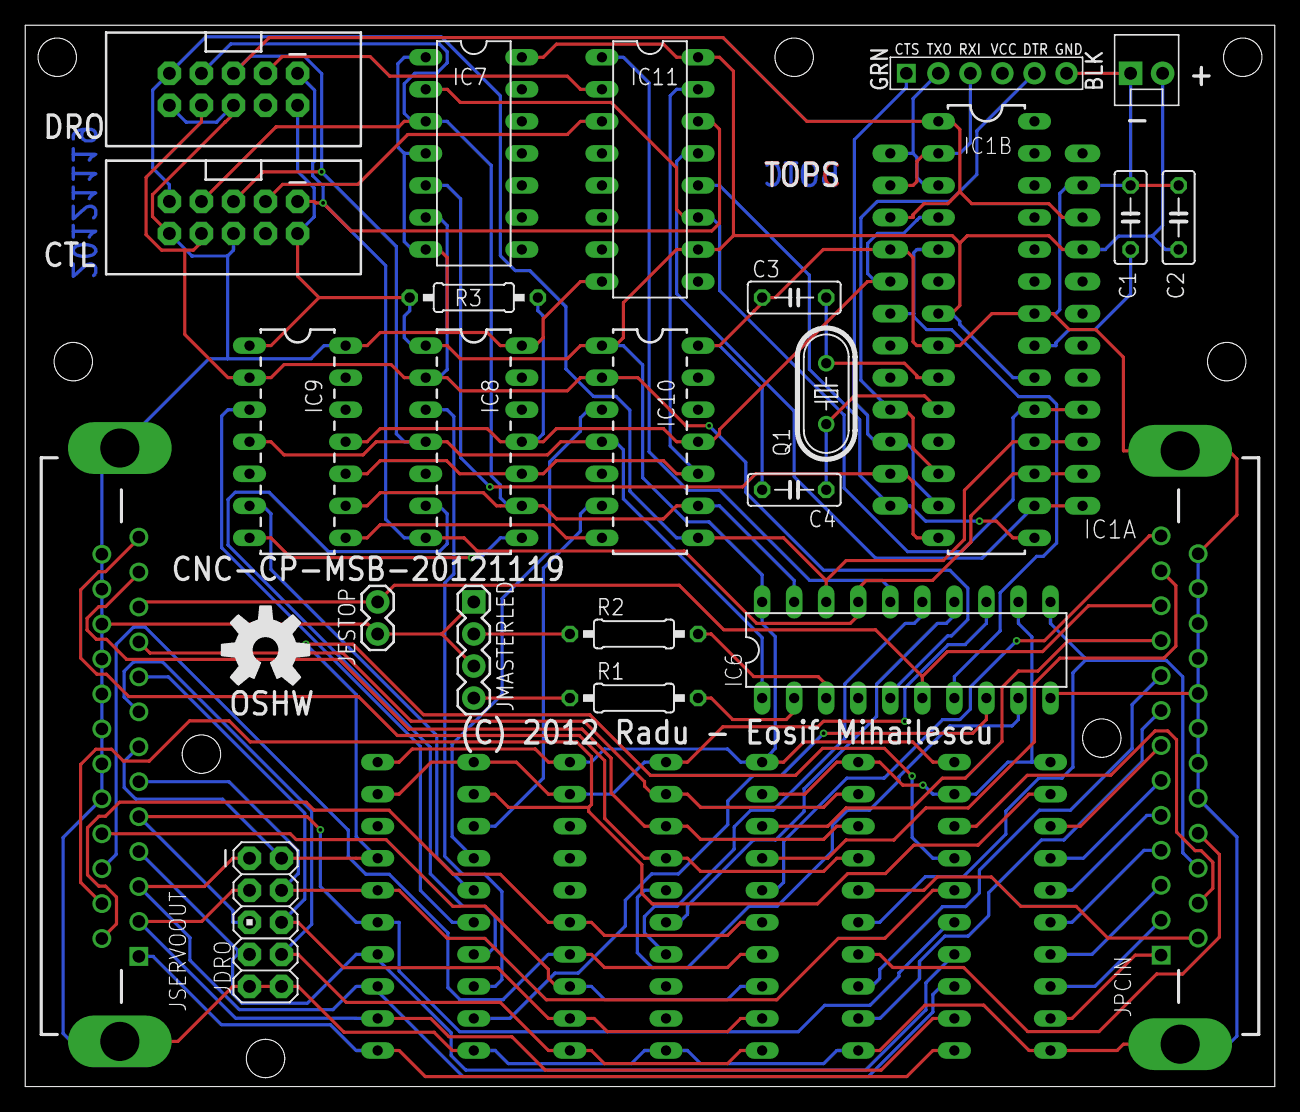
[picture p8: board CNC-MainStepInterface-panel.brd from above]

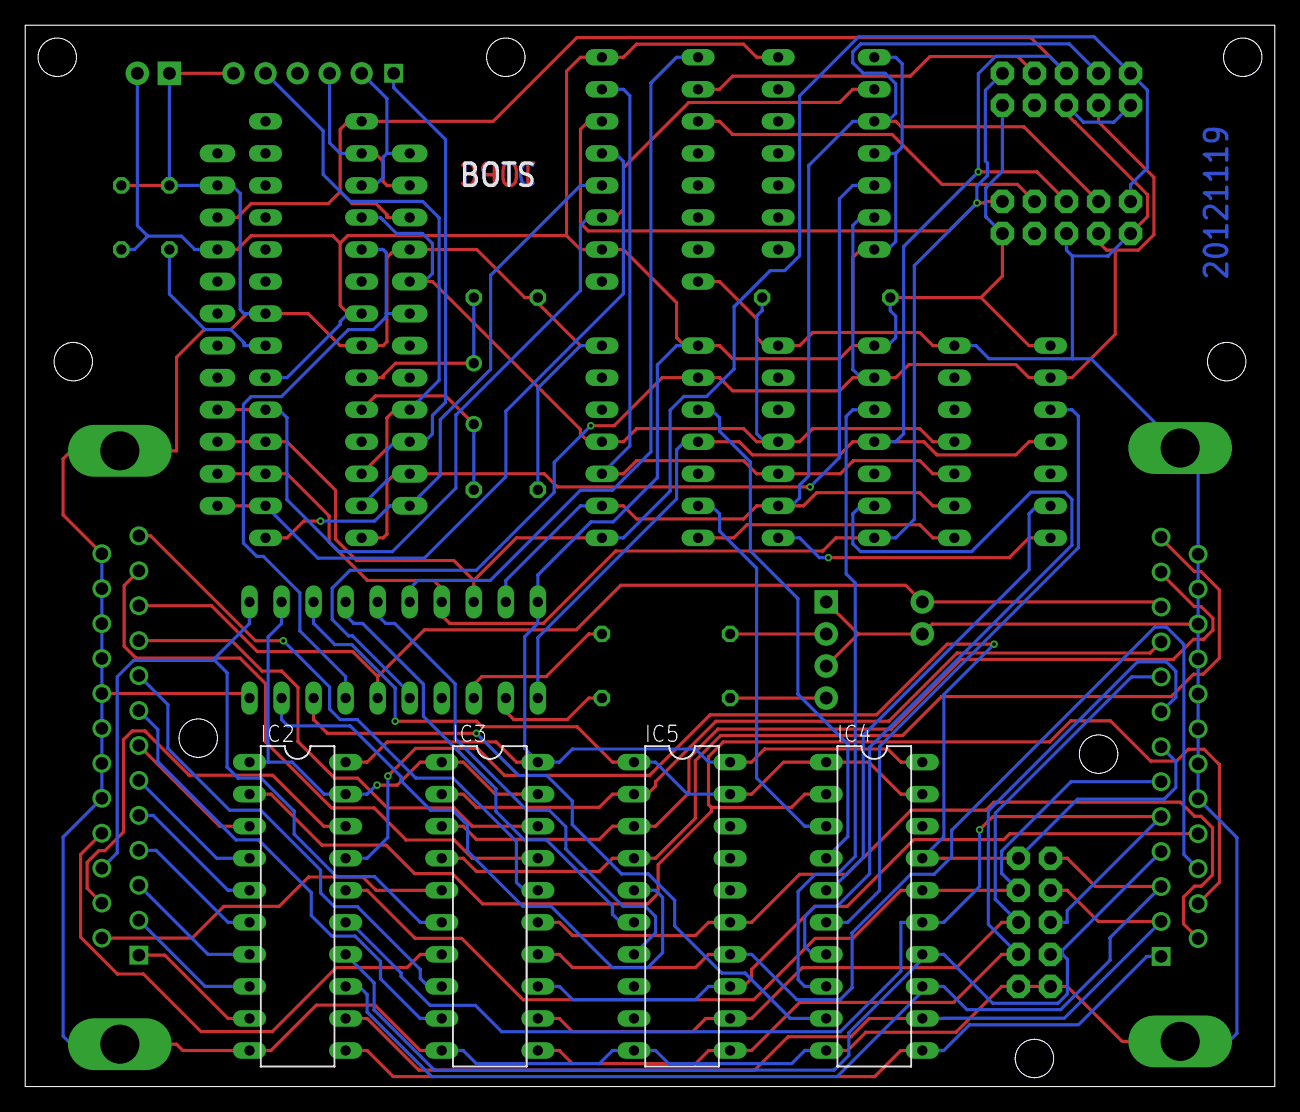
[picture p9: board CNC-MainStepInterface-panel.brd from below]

Board: 2 copper layers, 99.1 x 84.1 mm, 30 parts (4 on the bottom side), 78 nets.

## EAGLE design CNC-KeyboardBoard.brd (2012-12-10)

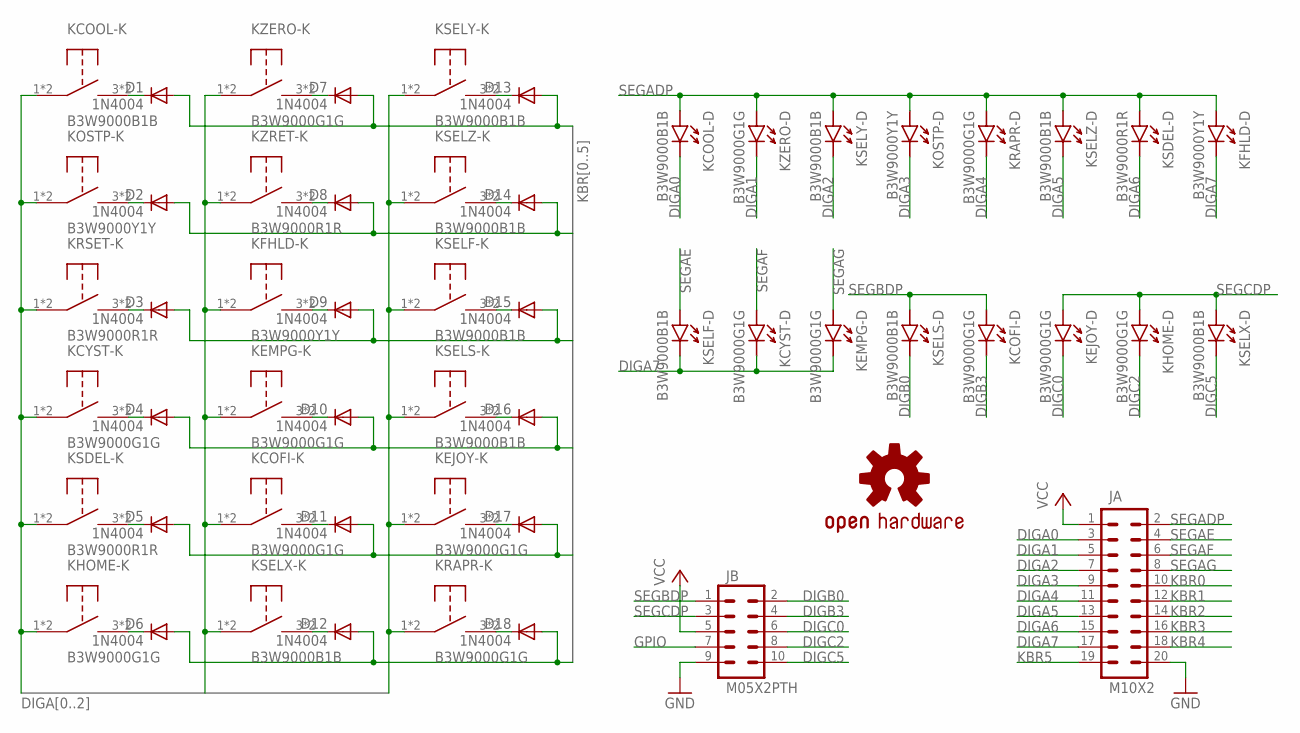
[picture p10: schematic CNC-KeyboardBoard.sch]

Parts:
D1, D2, D3, D4, D5, D6, D7, D8, D9, D10, D11, D12, D13, D14, D15, D16, D17, D18: 1N4004; DO41-10
JA: M10X2; 2X10
JB: M05X2PTH; AVR_ICSP
KCOFI: B3W9000G1G; OMRON_B3W90
KCOOL: B3W9000B1B; OMRON_B3W90
KCYST: B3W9000G1G; OMRON_B3W90
KEJOY: B3W9000G1G; OMRON_B3W90
KEMPG: B3W9000G1G; OMRON_B3W90
KFHLD: B3W9000Y1Y; OMRON_B3W90
KHOME: B3W9000G1G; OMRON_B3W90
KOSTP: B3W9000Y1Y; OMRON_B3W90
KRAPR: B3W9000G1G; OMRON_B3W90
KRSET: B3W9000R1R; OMRON_B3W90
KSDEL: B3W9000R1R; OMRON_B3W90
KSELF: B3W9000B1B; OMRON_B3W90
KSELS: B3W9000B1B; OMRON_B3W90
KSELX: B3W9000B1B; OMRON_B3W90
KSELY: B3W9000B1B; OMRON_B3W90
KSELZ: B3W9000B1B; OMRON_B3W90
KZERO: B3W9000G1G; OMRON_B3W90
KZRET: B3W9000R1R; OMRON_B3W90
U$1: SPARKFUN_OSHW-LOGOL; SPARKFUN_OSHW-LOGO-L

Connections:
DIGA0: JA.3, KCOOL.1, KCOOL.2, KCOOL.6 (K), KCYST.1, KCYST.2, KHOME.1, KHOME.2, KOSTP.1, KOSTP.2, KRSET.1, KRSET.2, KSDEL.1, KSDEL.2
DIGA1: JA.5, KCOFI.1, KCOFI.2, KEMPG.1, KEMPG.2, KFHLD.1, KFHLD.2, KSELX.1, KSELX.2, KZERO.1, KZERO.2, KZERO.6 (K), KZRET.1, KZRET.2
DIGA2: JA.7, KEJOY.1, KEJOY.2, KRAPR.1, KRAPR.2, KSELF.1, KSELF.2, KSELS.1, KSELS.2, KSELY.1, KSELY.2, KSELY.6 (K), KSELZ.1, KSELZ.2
DIGA3: JA.9, KOSTP.6 (K)
DIGA4: JA.11, KRAPR.6 (K)
DIGA5: JA.13, KSELZ.6 (K)
DIGA6: JA.15, KSDEL.6 (K)
DIGA7: JA.17, KCYST.6 (K), KEMPG.6 (K), KFHLD.6 (K), KSELF.6 (K)
DIGB0: JB.2, KSELS.6 (K)
DIGB3: JB.4, KCOFI.6 (K)
DIGC0: JB.6, KEJOY.6 (K)
DIGC2: JB.8, KHOME.6 (K)
DIGC5: JB.10, KSELX.6 (K)
GND: JA.20, JB.9
GPIO: JB.7
KBR0: D1.A, D7.A, D13.A, JA.10
KBR1: D2.A, D8.A, D14.A, JA.12
KBR2: D3.A, D9.A, D15.A, JA.14
KBR3: D4.A, D10.A, D16.A, JA.16
KBR4: D5.A, D11.A, D17.A, JA.18
KBR5: D6.A, D12.A, D18.A, JA.19
unnamed: D3.C, KRSET.3, KRSET.4
unnamed: D4.C, KCYST.3, KCYST.4
unnamed: D5.C, KSDEL.3, KSDEL.4
unnamed: D6.C, KHOME.3, KHOME.4
unnamed: D1.C, KCOOL.3, KCOOL.4
unnamed: D7.C, KZERO.3, KZERO.4
unnamed: D8.C, KZRET.3, KZRET.4
unnamed: D9.C, KFHLD.3, KFHLD.4
unnamed: D11.C, KCOFI.3, KCOFI.4
unnamed: D12.C, KSELX.3, KSELX.4
unnamed: D10.C, KEMPG.3, KEMPG.4
unnamed: D2.C, KOSTP.3, KOSTP.4
unnamed: D16.C, KSELS.3, KSELS.4
unnamed: D13.C, KSELY.3, KSELY.4
unnamed: D14.C, KSELZ.3, KSELZ.4
unnamed: D15.C, KSELF.3, KSELF.4
unnamed: D17.C, KEJOY.3, KEJOY.4
unnamed: D18.C, KRAPR.3, KRAPR.4
SEGADP: JA.2, KCOOL.5 (A), KFHLD.5 (A), KOSTP.5 (A), KRAPR.5 (A), KSDEL.5 (A), KSELY.5 (A), KSELZ.5 (A), KZERO.5 (A)
SEGAE: JA.4, KSELF.5 (A)
SEGAF: JA.6, KCYST.5 (A)
SEGAG: JA.8, KEMPG.5 (A)
SEGBDP: JB.1, KCOFI.5 (A), KSELS.5 (A)
SEGCDP: JB.3, KEJOY.5 (A), KHOME.5 (A), KSELX.5 (A)
VCC: JA.1, JB.5

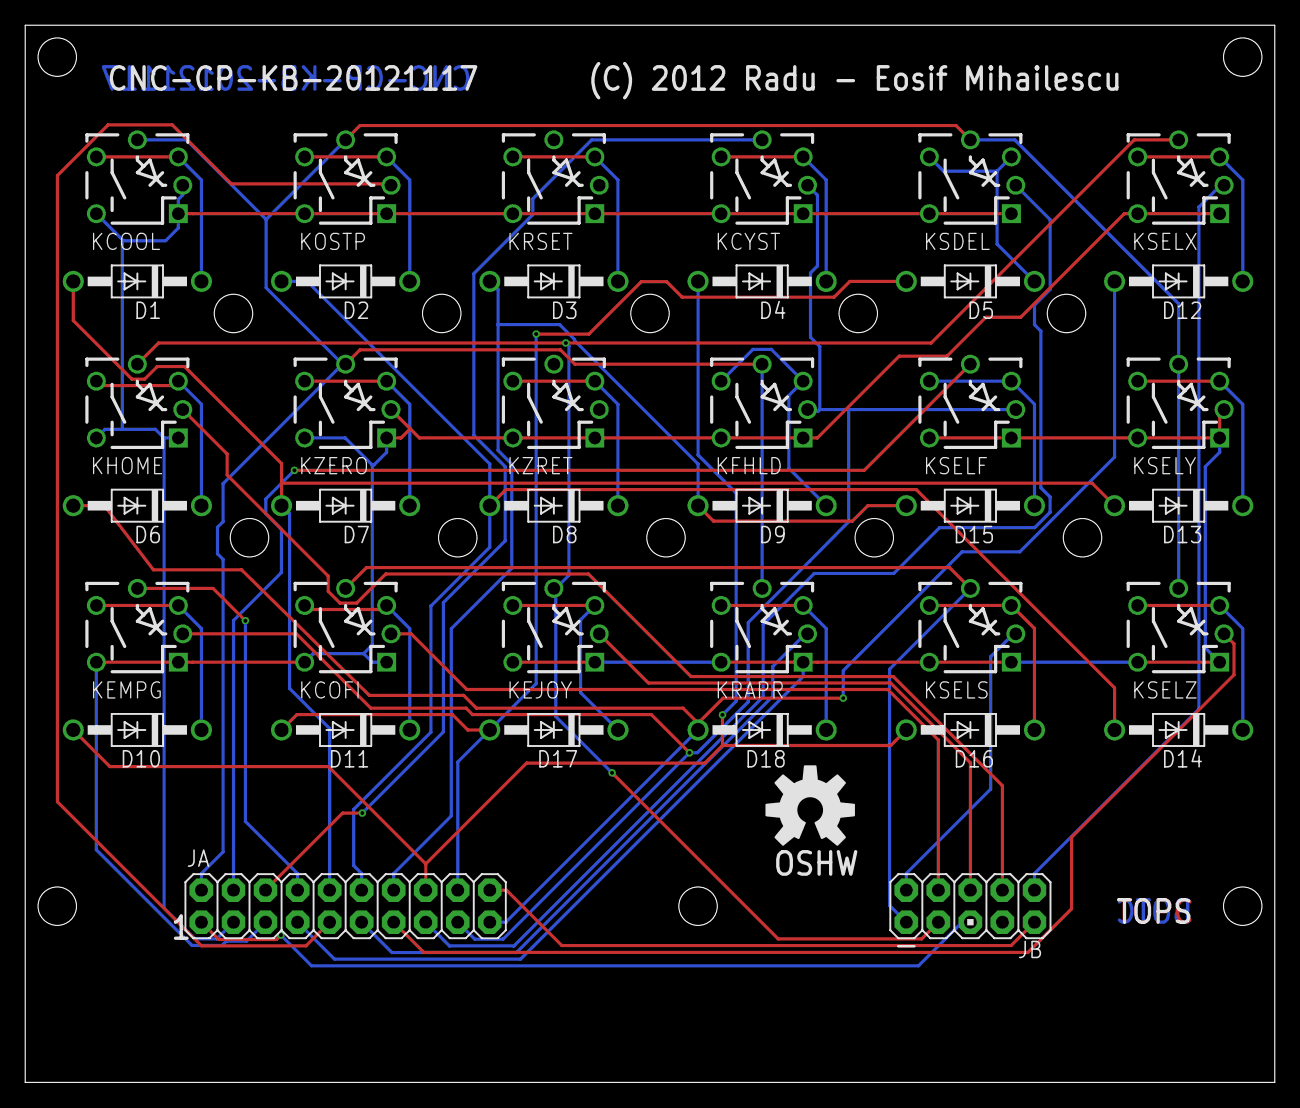
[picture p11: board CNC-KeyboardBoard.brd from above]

Board: 2 copper layers, 99.1 x 83.8 mm, 39 parts (0 on the bottom side), 45 nets.

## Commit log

2012-12-10 Initial commit: sync with local - initial version of all EDA files, corresponding to the 20121117/20121119 silkscreen version and to the 20121119 and 20121207 production runs - housekeeping: README, 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
    [CNC-ControlsBoard.brd, CNC-ControlsBoard.sch, CNC-DROBoard.brd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]
2012-12-10 Minor cosmetic changes, following production run. - added 45 degree bends to all 90 corners - straightened up two traces
    [CNC-MainStepInterface-panel.brd]
2012-12-10 BUGFIX: [XYZ]_LIMIT# not connected to [XYZ]_HOME# - when panelizing Main + Stepper + Interface on the same board, I forgot to make LIMIT the same as HOME. This will have to be reworked by hand during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
    [CNC-MainStepInterface-panel.brd, CNC-MainStepInterface-panel.sch]
2012-12-12 BUGFIX: Assembly variants - variant "20MHz" did not exclude "Arduino Pro Mini", as it should have. Fixed.
    [CNC-MainStepInterface-panel.brd, CNC-MainStepInterface-panel.sch]
2013-04-12 Housekeeping: - deleted obsolete Interface and Main -only boards and schematics. All these have been condensed in the MainStepInterface panel now - updated .gitignore to include library backups - upd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
    [CNC-ControlsBoard.brd, CNC-ControlsBoard.sch, CNC-InterfaceBoard.brd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]
2013-05-27 BUGFIX: 74LS4053 doesn't have the commons where you'd think it has - misleading symbol helped me mistake select inputs for common outputs - updated schematic, PCB update pending - this is probably no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
    [CNC-DROBoard.brd, CNC-DROBoard.sch]
2013-05-28 BUGFIX: Same 4053 mistake fixed on Controls board as well UPDATE: 27k instead of 33k for Riset as all LEDs can handle 20mA at 2.1V - routed both DRO and Controls in FreeRouting - updated silkscreen/a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
    [CNC-ControlsBoard.brd, CNC-ControlsBoard.sch, CNC-DROBoard.brd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]
2015-02-21 UPDATE: - added various devices and footprints I used for the BreadBoard-PSU project.
2015-02-23 BUGFIX: - DC Power Jack was missing >NAME and >VALUE.
2015-04-02 Size adjustments after the first qualification run: - 50% pad restring for some footprints instead of the 25% default, aids manual assembly.
2016-05-01 ENHANCEMENT: added a couple Schurter power-entry -related parts.
2016-05-01 Revert "ENHANCEMENT: added a couple Schurter power-entry -related parts."
    This reverts commit 4fb299129f2cc539ea6eccf9612a81f69a061dab.
    Because, why not? When GitHub can ruin your day, why not?
2016-05-01 ENHANCEMENT: added a couple Schurter power-entry -related parts. - take 2, because why not? When stupid design meets stupid implementation and they both decide your day is better ruined? - one day so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
2016-09-18 UPDATE: minor changes to footprints
2016-09-18 Added other bits and pieces from other, related, CNC projects.
    [cnc-data-panel.sch, cnc-opto-board.brd, cnc-opto-board.sch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]
2016-09-20 UPDATE: sized board outline to fit DIN rail mount frame and routed.
    [cnc-opto-board.brd, cnc-opto-board.sch]
2016-09-21 RTM: aesthetics and shrink-wrap for the opto board, ready for tape-out.
    [cnc-opto-board.brd, cnc-opto-board.sch]
2017-06-23 UPDATE: added ST LED2472G in TQFP48 - this will need to become TQFP48-EP - MLPQ40 version will also need to be added.
2017-12-19 UPDATE: refined symbol and footprint for PE42742
2018-01-30 UPDATE: added TE IM43GR RF-compatible latching relay.
2018-02-02 UPDATE: added Microchip MTS62C19A, stepper driver.
2018-02-02 UPDATE: Added ON LV8549M, stepper driver.

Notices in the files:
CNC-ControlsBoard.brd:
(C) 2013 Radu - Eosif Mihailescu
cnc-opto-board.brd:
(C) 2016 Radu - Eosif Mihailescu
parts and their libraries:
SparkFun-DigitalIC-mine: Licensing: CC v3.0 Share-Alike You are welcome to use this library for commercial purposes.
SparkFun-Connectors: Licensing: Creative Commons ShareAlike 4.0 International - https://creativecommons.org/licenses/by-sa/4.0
